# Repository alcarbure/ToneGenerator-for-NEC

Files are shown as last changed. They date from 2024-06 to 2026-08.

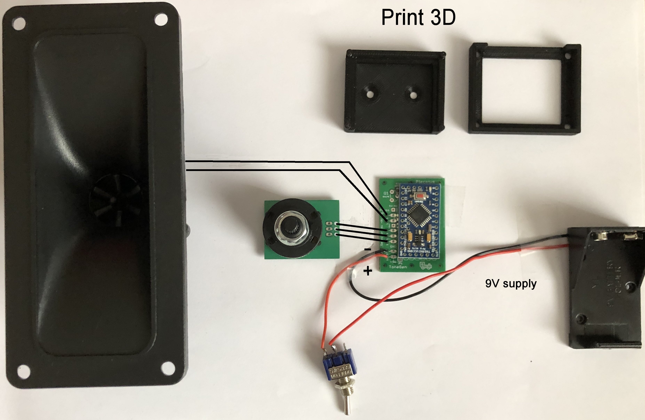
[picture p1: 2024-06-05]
AtWork/Wiring diagram/Wiring V1.jpeg

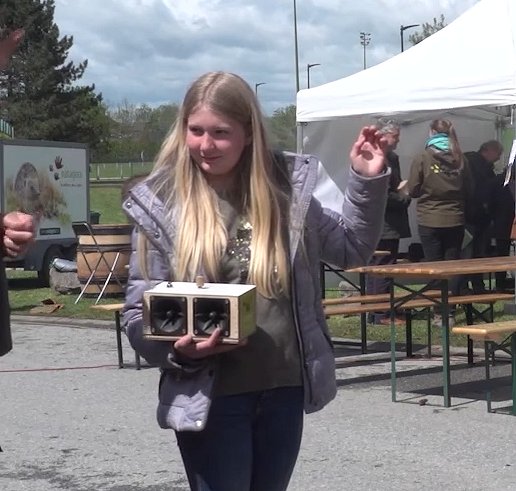
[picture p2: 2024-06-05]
AtWork/Images/demo-NEC.jpg

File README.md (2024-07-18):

# ToneGenerator for NEC

[Project sample](AtWork/Images/Presentation.jpg)

Il s’agit de réaliser un petit générateur de son et d’ultrason afin de faire connaitre au public, le monde des chauve-souris lors des NEC ( nuit européenne des chauve-souris).

This involves creating a small sonic and ultrasonic generator in order to raise awareness of the world of bats during the NEC (European Bat Night).

_____________________________________________________________

## Projet initial : 
La première version du générateur de son/ultarson étais axée sur un NE555 bien connus de nos ancien dont je fais partie, mais le principal inconvénient est sa stabilité dans le temps ceci dû au composant utilisé pour la génération du signal rectangulaire analogique. De nombreux utilisateur se plaignais des erreurs de fréquence assez importante dû au vieillissement des résistances du contacteur rotatif et des condensateurs. 
## Project actuel : 
Etant donné le nombre de réparation qui m’étais demandé, j’ai décidé de mettre ce projet au gout du jour. Dès lors, J’ai basé ce nouvel opus sur un Arduino Pro-Mini (5V) qui lui restera suffisamment stable en fréquence grâce a son Xtal de 16Mhz et donc en faire aussi un appareil de calibrage pour les anciens détecteurs tel que les anciens Petterson ou de vérifier l’état de vos micro ultrasonique. J’ai donc gardé cette idée axée autour du contacteur rotatif (un potentiomètre linaire peut aussi faire l’affaire) avec une combinaison permettant d’atteindre une fréquence maximum de 32KHz, bien sur il faut que le HP piezo arrive à diffuser cette fréquence. 
Ce montage fonctionne sur une pile de 9V, mais peut-être facilement adapté pour une alimentation 12v en y ajoutant un régulateur AMS1117—5V (ensemble D1-IC1).

### Descriptif : 
L’ensemble est axé sur l’Arduino Pro Mini soudé sur un petit circuit imprimé que vous trouverais dans le dossier PCB-SMD. Il est possible de faire soi-même ce circuit en utilisant d’anciennes résistances plutôt que l’utilisation des composant de surface. Mais l’idée est de faire fabriquer l’ensemble de vos circuits par une société tel que JLCPCB qui propose le montage des composants SMD et de le tropicaliser plus facilement avec un vernis adéquat. Il faut compter à ce jour (2024) +/-24€ + port pour 20 pièces. Il vous restera à souder le contacteur rotatif, l’Arduino et quelque fils entre les autres composants du projet.
### PCB & Gerber
Dans le dossier **Dossier -JLCPCB** se trouve, les fichiers pour JLCPCB ou votre fabriquant favori,
Vous y trouverais aussi les fichiers Gerber, les fichier KidCad 7.xx ainsi que ses librairies et une version PDf de ces fichiers.

### AtWork
Ce dossier comprend la liste du matériel dont vous avez besoin, le plan de câblage, un exemple de plan d’assemblage du boitier en bois, le STL pour imprimer le support du circuit si vous ne voulez pas le coller au boitier et quelques images.
Imprimez ‘pannel.jpg’ et plastifiiez-le. Il sera la face supérieure sur laquelle sera fixé l’interrupteur et le commutateur rotatif à 12 positions 
### Software
Inutile de dire que le software se trouve dans ce dossier 😉

Je vous souhaite bien du plaisir pour réaliser ce petit projet cher au passionné des chauve-souris dont je fais partie dans le groupe des volontaire Plecotus de Natagora Belgique. 

___________________________________________________________________________________________________ 

## Initial project: 
The first version of the sonic/ultarsonic generator was based on a NE555 well known to our elders of which I am a part, but the main disadvantage is its stability over time, due to the component used for the generation of the analog rectangular signal. Many users complained of fairly large frequency errors due to the aging of the rotary contactor resistors and capacitors. 
## Current project: 
Given the number of repairs that were required of me, I decided to bring this project up to date. From then, I based this new opus on an Arduino Pro-Mini (5V) which will remain sufficiently stable in frequency wit Xtal 16Mhz inside and therefore also make it a calibration device for old detectors such as the old Petterson or check the condition of your ultrasonic microphone. I therefore kept this idea centered around the rotary contactor (a linear potentiometer can also used) with a combination allowing a maximum frequency of 32KHz to be reached, of course the piezo speaker must be able to diffuse this frequency. This assembly runs on a 9V battery, but can easily be adapted for a 12v power supply by adding an AMS1117—5V regulator (D1-IC1 set). 
### Description:
 The whole thing is focused on the Arduino Pro Mini soldered on a small printed circuit that you would find in the PCB-SMD folder. It is possible to make this circuit yourself using old resistors rather than using surface components. But the idea is to have all of your circuits manufactured by a company such as JLCPCB which offers the assembly of SMD components and to tropicalize it more easily with a suitable varnish. As of today (2024), you need to count +/-24€ + shipping for 20 pieces. You will still have to solder the rotary contactor, the Arduino and some wires between the other components of the project. 
### PCB & Gerber
In the floder **Dossier-JLCPCB** you will find the files for JLCPCB or your favorite manufacturer, You will also find Gerber files, KidCad 7.xx files as well as its libraries and a PDF version of these files. 
### AtWork
This file includes the list of materials you need, the wiring plan, an example of an assembly plan for the wooden case, the STL to print the circuit support if you do not want to glue it to the case and some images. 
Print ‘pannel.jpg’ and laminate it. It will be the upper face on which the switch and the 12-positions rotary switch will be fixed. 
 
###Software
Needless to say, the software is in this folder 😉
I wish you a lot of fun carrying out this little project dear to the bat enthusiast of which I am a part in the group of Plecotus volunteers from Natagora Belgium.

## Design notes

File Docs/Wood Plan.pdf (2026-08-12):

### Plan de découpe pour un panneau de 1.2m/0.61m en contreplaqué de 8mm Cutting plan for a 1.2m/0.61m panel in 8mm plywood

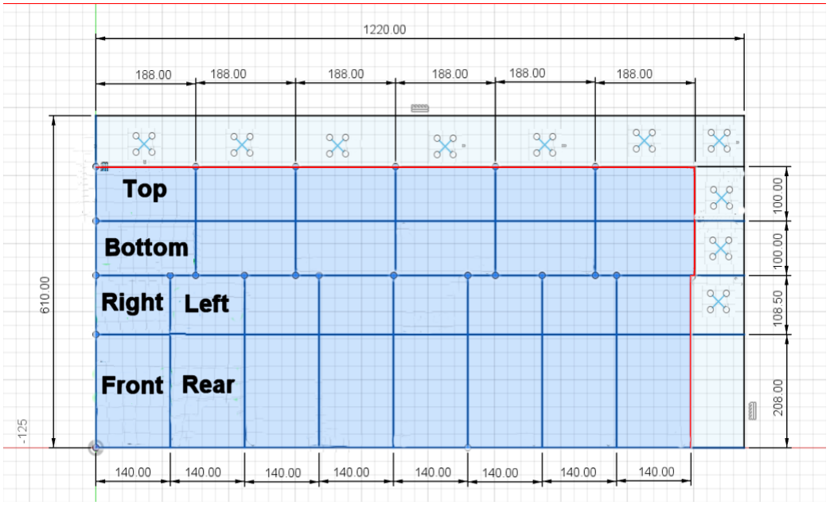
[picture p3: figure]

Top -> Panneau supérieur avec le sélecteur rotatif et l’interrupteur - Top panel with rotary selector and switch
Front -> Face avant supportant le ou les HP - Front panel supporting the HP(s)
Rear - Panneau arrière supportant la pile 9V en retrait de 2cm - Rear panel supporting the 9V battery set back 2cm
NB : Ne pas coller le panneau supérieur, il permet l'accès et sera vissé - Do not glue the top panel, it allows access and will be screwed

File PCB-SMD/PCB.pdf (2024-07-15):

## PCB Selector 12/1P

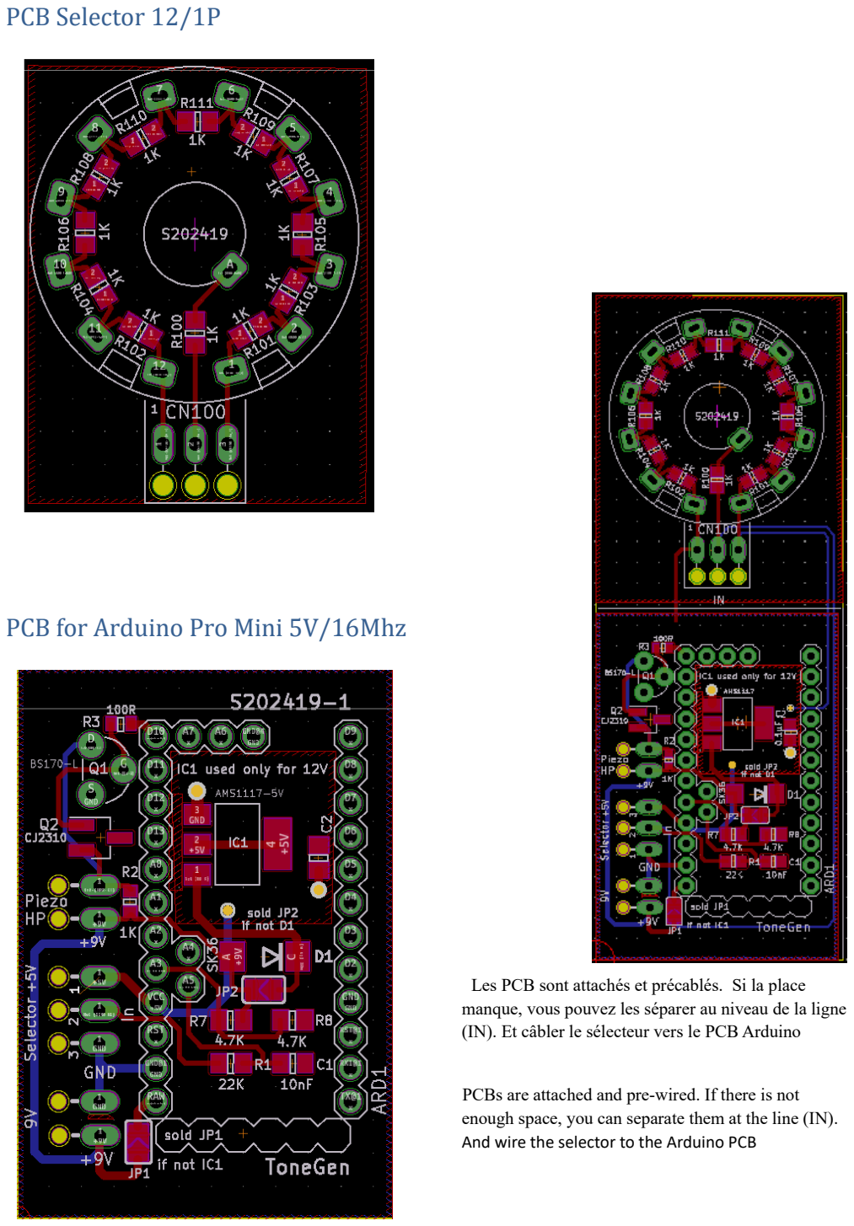
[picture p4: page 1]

## PCB for Arduino Pro Mini 5V/16Mhz

Les PCB sont attachés et précablés. Si la place manque, vous pouvez les séparer au niveau de la ligne (IN). Et câbler le sélecteur vers le PCB Arduino

PCBs are attached and pre-wired. If there is not enough space, you can separate them at the line (IN). And wire the selector to the Arduino PCB

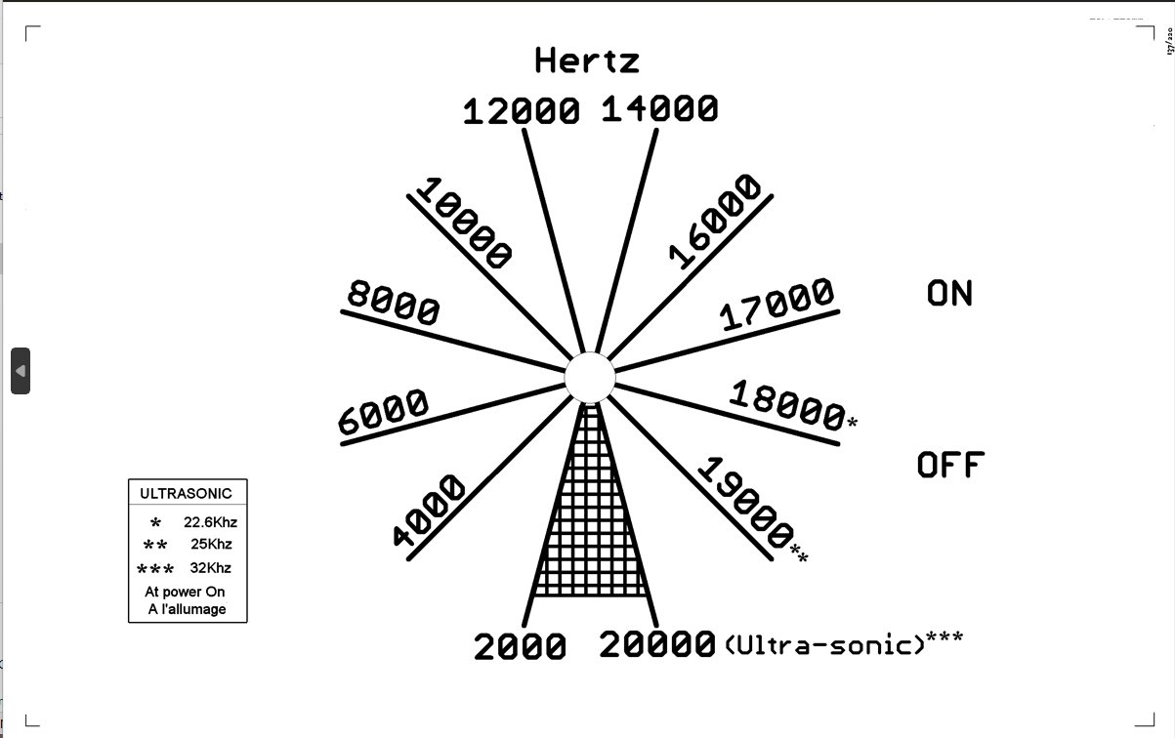
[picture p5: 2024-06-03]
AtWork/Wood Box/Pannel.jpg

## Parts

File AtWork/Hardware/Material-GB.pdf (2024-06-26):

Ref | Nbr | Description | Dealer | Price 6/2024 | Other dealer
HP | 1 | Tweeter piezo 20-20Khz | https://fr.aliexpress.com/item/32832017370.html | 8€/2 | https://fr.aliexpress.com/item/1005006384028605.html
Or This HP | 2 | Tweeter piezo 20-20Khz | https://fr.aliexpress.com/item/1005006989121243.html | 4,5€/2 | https://fr.aliexpress.com/item/1005006124053121.html
ARD | 1 | Arduino Pro Mini 5V/16MHz | https://fr.aliexpress.com/item/1005006160649217.html | 2,50 € | https://fr.aliexpress.com/item/1005006974788642.html
If needed | | Serial interface FT232RL or other for Arduino | https://fr.aliexpress.com/item/1005006625544072.html | 2,00 €
SW | 1 | Power Switch On/Off | https://fr.aliexpress.com/item/1005005989323670.html | 2,45€ / 5 | https://fr.aliexpress.com/item/1005004227130782.html
S Batt | 1 | 9V Battery clip support | https://fr.aliexpress.com/item/32945156022.html | 0,15 € | https://fr.aliexpress.com/item/1005004143955472.html
J100 | 1 | RS26 1 Pole Position 12 (Rotary selector) + button | https://fr.aliexpress.com/item/4000119826725.html | 2,50 € | https://fr.aliexpress.com/item/1005002457162436.html
Wire | 1 | 4/5 color AWG24 / 25m for more generator | https://fr.aliexpress.com/item/1005005048098404.htm
PCB | 1 | PCB pre-monted (price by 20 units) | JLCPCB | 3,00 € | jlcpcb.com
| | | Dont forget --> + port | xxx

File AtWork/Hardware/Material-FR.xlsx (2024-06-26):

Ref | Nbr | Description | Dealer | Price 6/2024 | Other dealer
HP | 1 | Tweeter piezo 20-20Khz | https://fr.aliexpress.com/item/32832017370.html | 4.00 € | https://fr.aliexpress.com/item/1005006384028605.html
Ou ces HP | 2 | Tweeter piezo 20-20Khz | https://fr.aliexpress.com/item/1005006989121243.html | 2.50 € | https://fr.aliexpress.com/item/1005006124053121.html
ARD | 1 | Arduino Pro Mini 5V/16MHz (avec header) | https://fr.aliexpress.com/item/1005006160649217.html | 2.50 € | https://fr.aliexpress.com/item/1005006974788642.html
SI besoin |  | Interface FT232RL or autre pour programmer Arduino | https://fr.aliexpress.com/item/1005006625544072.html | 2.00 €
SW | 1 | Interrupteur a bascule On/Off | https://fr.aliexpress.com/item/1005005989323670.html | 0.50 € | https://fr.aliexpress.com/item/1005004227130782.html
S Batt | 1 | Support pile 9V à clipser | https://fr.aliexpress.com/item/32945156022.html | 0.15 € | https://fr.aliexpress.com/item/1005004143955472.html
J100 | 1 | RS26 1 Pole Position 12 (sélecteur rotatif) + bouton | https://fr.aliexpress.com/item/4000119826725.html | 2.50 € | https://fr.aliexpress.com/item/1005002457162436.html
Fil | 1 | 4/5 couleur AWG24 / 25m pour plusieurs coffrets | https://fr.aliexpress.com/item/1005005048098404.htm
PCB | 1 | PCB précablè (prix par 20 pièces) ( by 20 units) | JLCPCB | 3.00 € | jlcpcb.com
 |  |  | Ne pas oublier --> le port (pas compris dans les prix indicatif) | xxx
 |  |  |  | 17.15 €

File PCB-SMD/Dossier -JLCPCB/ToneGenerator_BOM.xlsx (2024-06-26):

Item | Designator | Qty | Manufacturer | MFR.Part # | LCSC Part # | Description / Value | Footprint | Comment | Part
1 | C1 | 1 | Samsung Electro-Mechanics | CL21B103KBANNNC | C1710 | 50V 10nF X7R ±10% 0805 Multilayer Ceramic Capacitors MLCC - SMD/SMT ROHS | 0805 |  | Basic
2 | C2 | 1 | YAGEO | CC0805KRX7R9BB104 | C49678 | 50V 100nF X7R ±10% 0805 Multilayer Ceramic Capacitors MLCC - SMD/SMT ROHS | 0805 |  | Basic
3 | R1 | 1 | UNI-ROYAL(Uniroyal Elec) | 0805W8F2202T5E | C17560 | 125mW Thick Film Resistors 150V ±100ppm/℃ ±1% 22kΩ 0805 Chip Resistor - Surface Mount ROHS | 0805 |  | Basic
4 | R2 | 1 | UNI-ROYAL(Uniroyal Elec) | 0603WAF1001T5E | C21190 | 100mW Thick Film Resistors 75V ±100ppm/℃ ±1% 1kΩ 0603 Chip Resistor - Surface Mount ROHS | 0603 |  | Basic
5 | R3 | 1 | UNI-ROYAL(Uniroyal Elec) | 0603WAF1000T5E | C22775 | 100mW Thick Film Resistors 75V ±1% ±200ppm/℃ 100Ω 0603 Chip Resistor - Surface Mount ROHS | 0603 |  | Basic
6 | R7, R8 | 1 | UNI-ROYAL(Uniroyal Elec) | 0805W8F4701T5E | C17673 | 125mW Thick Film Resistors 150V ±100ppm/℃ ±1% 4.7kΩ 0805 Chip Resistor - Surface Mount ROHS | 0805 |  | Basic
7 | R100,R108,R102,R105, R101,R106,R109,R107, R104,R103,R111,R110 | 12 | UNI-ROYAL(Uniroyal Elec) | 0805W8F1001T5E | C17513 | 125mW Thick Film Resistors 150V ±100ppm/℃ ±1% 1kΩ 0805 Chip Resistor - Surface Mount ROHS | 0805 |  | Basic
8 | Q2 | 1 | Jiangsu Changjing Electronics Technology Co., Ltd. | CJ2310 | C75882 | 60V 3A 105mΩ@10V,3A 350mW 2V 1PCSNChannel SOT-23 MOSFETs ROHS | SOT-23 |  | Extended

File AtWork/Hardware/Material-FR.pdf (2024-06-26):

https://fr.aliexpress.com/item/1005006384028605.htmlhttps://fr.aliexpress.com/item/1005006124053121.htmlhttps://fr.aliexpress.com/item/1005006974788642.html

https://fr.aliexpress.com/item/1005004227130782.htmlhttps://fr.aliexpress.com/item/1005004143955472.htmlhttps://fr.aliexpress.com/item/1005002457162436.html

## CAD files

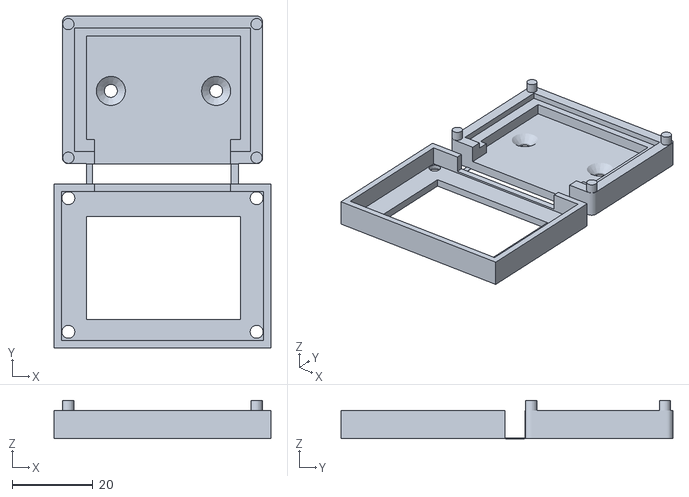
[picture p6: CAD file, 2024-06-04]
AtWork/Printer3D/ToneGenerator-PLA.stl
53.5 x 82.0 x 9.50

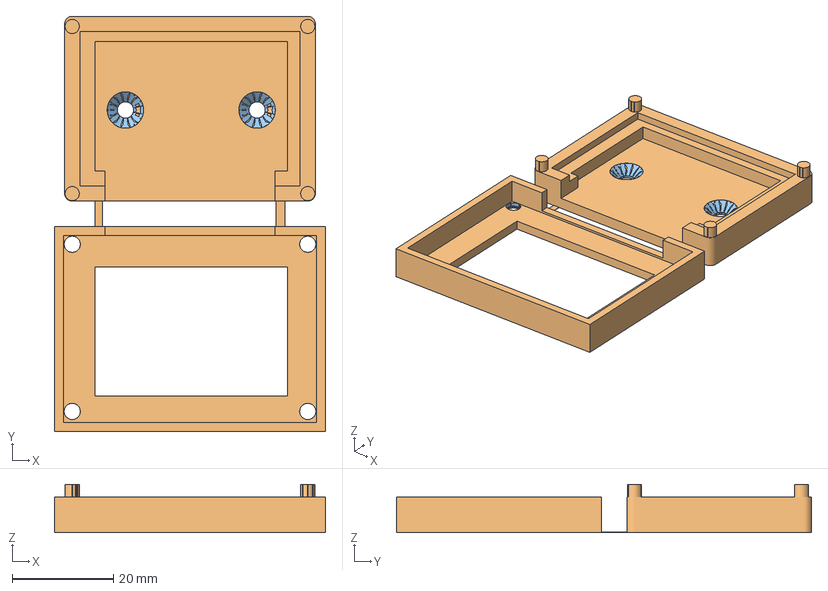
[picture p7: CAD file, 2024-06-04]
AtWork/Printer3D/ToneGenerator.FCStd
53.5 x 82.0 x 9.50 mm
Chamfer002 (Meshed)

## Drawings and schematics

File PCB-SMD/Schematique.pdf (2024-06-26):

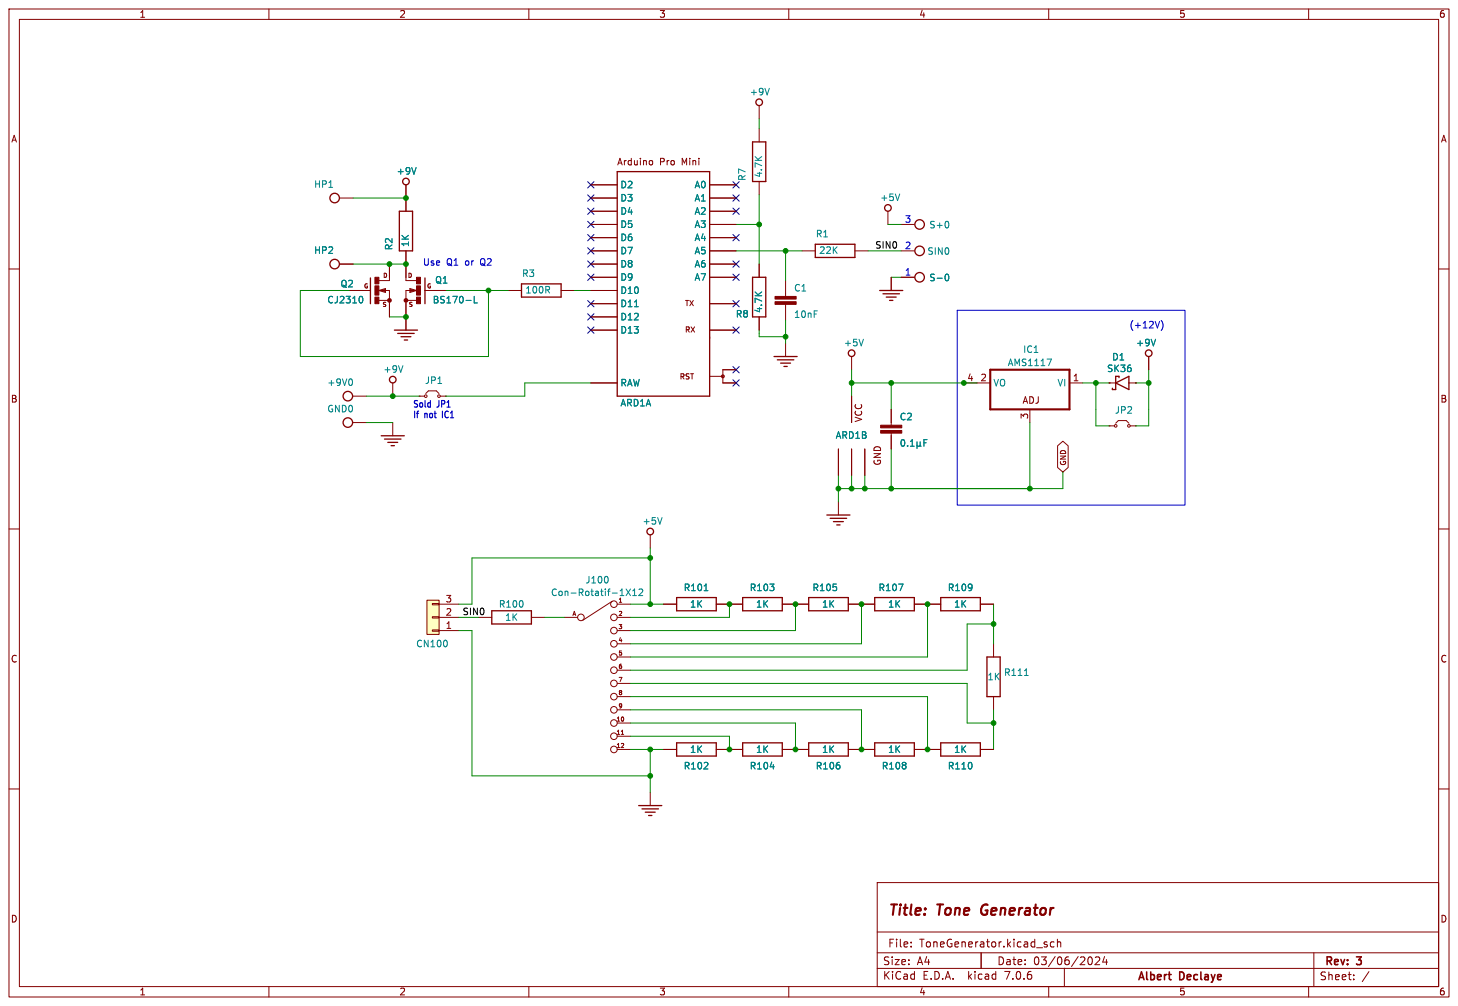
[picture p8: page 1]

Arduino Pro Mini RSTRX
TXA0A1A2A3A4A5A6A7 D10 D11 D12 D13 D2 D3 D4 D5 D6 D7 D8 D9 RAW

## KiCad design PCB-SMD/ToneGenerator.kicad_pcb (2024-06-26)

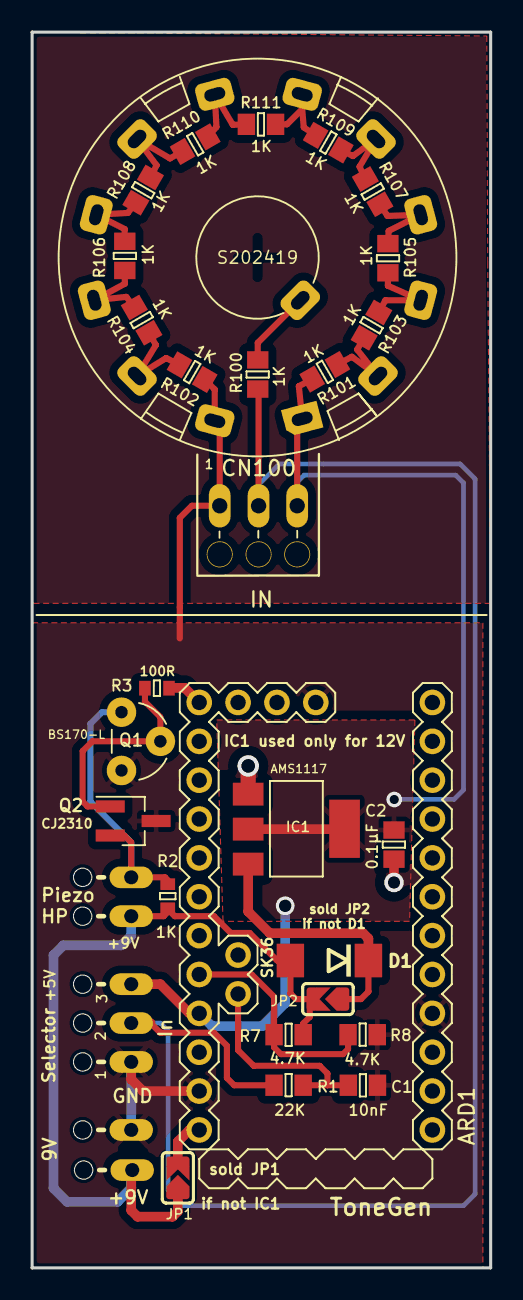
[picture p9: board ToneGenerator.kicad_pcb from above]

Board: 2 copper layers, 30.0 x 80.8 mm, 35 parts (0 on the bottom side), 22 nets.

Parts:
+9V0: AMP-01; W1
ARD1: ARDUINO_PRO_MINI_LT-2; ARDUINO_PRO_MINI_V2_LT
C1: 10nF; 0805
C2: 0.1µF; 0805
CN100: IN; W3X
D1: SK36; DO214AA
GND0: AMP-01; W1
HP1, HP2: AMP-01; W1
IC1: AMS1117; SOT-223
J100: Con-Rotatif-1X12; RS26-1P12T
JP1, JP2: JP1-ARROW_NOPASTE; SOLDERJUMPER_ARROW_NOPASTE
Q1: BS170-L; SOT54E-L
Q2: CJ2310; SOT-23_Handsoldering
R1: 22K; 0805
R2: 1K; 0603
R3: 100R; 0603
R7, R8: 4.7K; 0805
R100, R101, R102, R103, R104, R105, R106, R107, R108, R109, R110, R111: 1K; 0805
S+0: AMP-01; W1
S-0: AMP-01; W1
SIN0: AMP-01; W1

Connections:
+5V: ARD1.VCC (VCC@2), C2.1, CN100.3, IC1.2 (VO), IC1.4 (VO1), J100.1, R101.1, S+0.1 (KL)
+9V: +9V0.1 (KL), D1.A, HP1.1 (KL), JP1.1, JP2.2, R2.2, R7.2
/SIN0: CN100.2, R1.2, R100.2, SIN0.1 (KL)
GND: ARD1.GND, ARD1.GND@1, ARD1.GND@4, C1.2, C2.2, CN100.1, GND0.1 (KL), IC1.3 (ADJ), J100.12, Q1.S, Q2.3 (S), R8.1, R102.1, S-0.1 (KL)
unnamed: ARD1.A3, R7.1, R8.2
unnamed: ARD1.A5, C1.1, R1.1
unnamed: ARD1.D10, R3.2
unnamed: ARD1.RAW, JP1.2
unnamed: D1.C (K), IC1.1 (VI), JP2.1
unnamed: HP2.1 (KL), Q1.D, Q2.2 (D), R2.1
unnamed: J100.2, R101.2, R103.1
unnamed: J100.3, R103.2, R105.1
unnamed: J100.4, R105.2, R107.1
unnamed: J100.5, R107.2, R109.1
unnamed: J100.6, R109.2, R111.2
unnamed: J100.7, R110.2, R111.1
unnamed: J100.8, R108.2, R110.1
unnamed: J100.9, R106.2, R108.1
unnamed: J100.10, R104.2, R106.1
unnamed: J100.11, R102.2, R104.1
unnamed: J100.A, R100.1
unnamed: Q1.G, Q2.1 (G), R3.1

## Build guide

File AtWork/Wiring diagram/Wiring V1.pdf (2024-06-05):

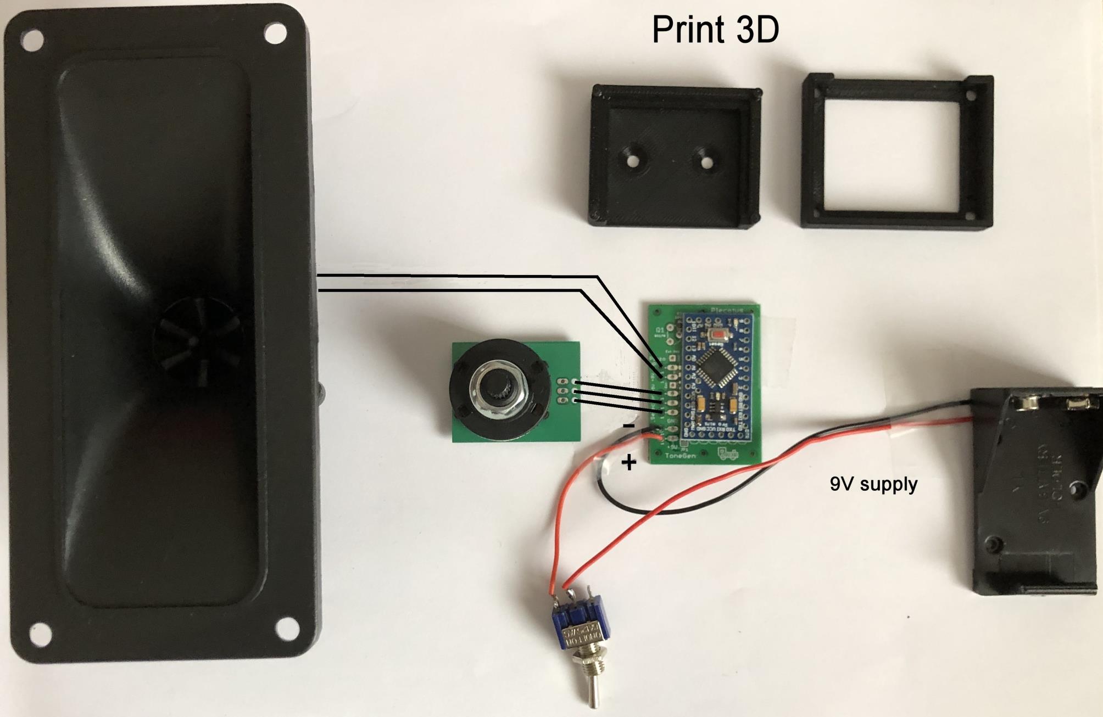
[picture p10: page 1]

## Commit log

2024-06-03 Ajout d’informations sur la finalité du projet
2024-06-03 Project Update
    [ToneGenerator-B_Cu.gbr, ToneGenerator-B_Mask.gbr, ToneGenerator-B_Paste.gbr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]
2024-06-04 Upadte site
    [ToneGenerator-PLA.stl, ToneGenerator.FCStd]
2024-06-26 PCB Update
    [Material-FR.xlsx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]
2024-06-26 Update hardware
    [Material-FR.xlsx, Material-GB.xls]
